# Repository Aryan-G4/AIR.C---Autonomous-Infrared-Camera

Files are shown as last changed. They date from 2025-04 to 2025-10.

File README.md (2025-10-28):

# AIDA: Automated Infrared Detection Aperture



A self-controlled, fire-detecting robot that uses infrared imaging and wireless communication to identify and alert the presence of fire in real time and wirelessly report it to a host computer.  
This project combines mechanical motion, embedded firmware, and networked communication into a compact autonomous system.
It has been designed with the inspiration of removing multiple traditional ceiling fire detectors, replacing them with one robot to monitor an entire room.
---

## Overview


The robot continuously rotates back and forth with a 360 Degree angle using a stepper motor while scanning its surroundings with an infrared camera module.  
When a fire source is detected, it stops rotating and sends a wireless alert to another ESP32 reciever using the ESP-NOW protocol. 
Multiple Fire Monitors can transmit to the reciever 

---

## Features

- 360° autonomous rotation via stepper motor control (NEMA17 + TP339 controller)
- Real-time fire detection using an **MLX90640 infrared camera**  
- Wireless communication via **ESP-NOW** between two ESP32 devkits  
- Powered by a **5V portable phone charger** for mobility  and free rotation, as well as a stepper motor driver powered by a +24V wall adapter
- Automatic halt and alert transmission upon fire detection  
- Modular hardware architecture for easy debugging and extension  

---
## Solidworks model (3D printed)



## Physical Model



## Hardware Components

| Component | Description | Purpose |
|---|---|---|
| **ESP32 DevKit V1** | Wi-Fi + Bluetooth microcontroller | Main processing and communication unit |
| **MLX90640 IR Camera** | 32×24 thermal imaging sensor | Detects fire via infrared radiation |
| **TP339 Stepper Motor Driver** | Stepper control interface | Controls swivel rotation of the robot |
| **Stepper Motor (NEMA 17)** | Bipolar motor | Rotates the robot base |
| **5V Portable Power Bank** | External USB supply | Powers the ESP32 and all connected low-voltage peripherals |
| **Custom Mount and Chassis** | 3D-printed Strucutre | Holds the electronics and allows the NEMA17 to rotate the camera and devkit to monitor the room |

---

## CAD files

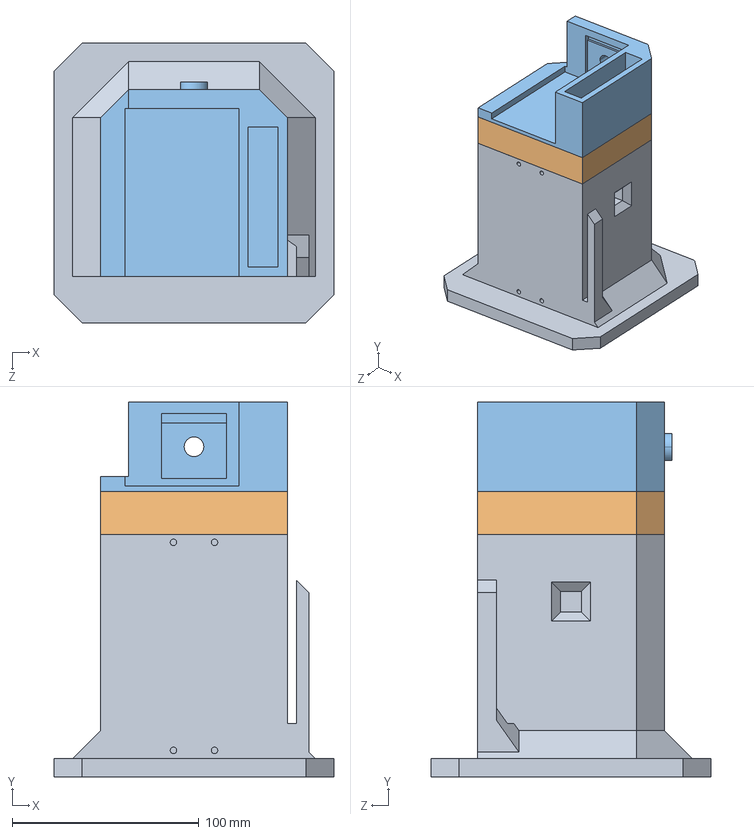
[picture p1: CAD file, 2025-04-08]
Solidworks_CAD_design/3D_Printing_Outbox/STEP_214 Files/Middle_Chassis_v2_UpperChassis_v1.STEP
150.0 x 201.0 x 150.0 mm
BasePrototype
Part1^MASTER-ASSEMBLY
Part2^MASTER-ASSEMBLY

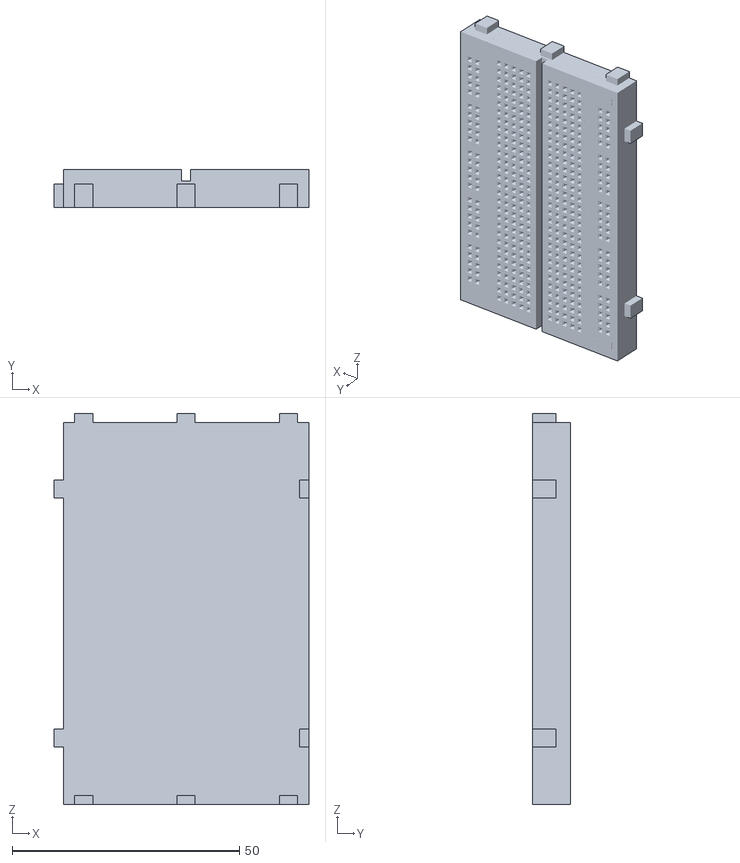
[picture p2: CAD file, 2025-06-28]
Solidworks_CAD_design/Breadboard 400.stl
56.0 x 8.41 x 86.0

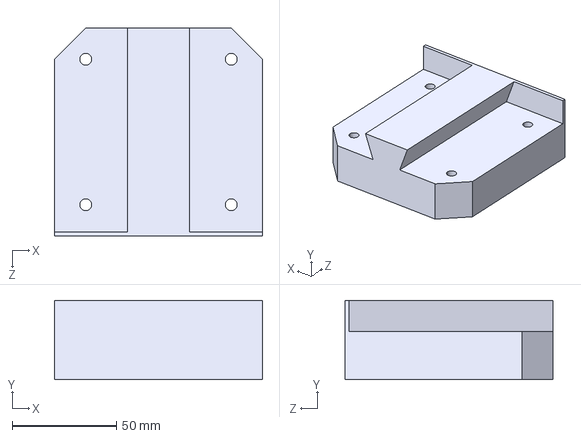
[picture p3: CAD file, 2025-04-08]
Solidworks_CAD_design/3D_Printing_Outbox/STEP_214 Files/Middle_Chassis_v1.STEP
100.0 x 38.0 x 100.0 mm

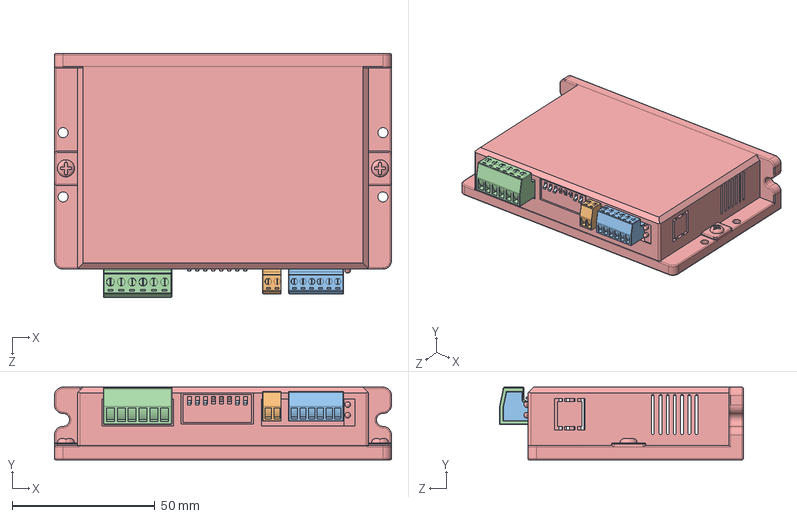
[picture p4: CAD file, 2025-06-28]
Solidworks_CAD_design/DM542T(V4.0).STEP
118.0 x 25.5 x 85.4 mm

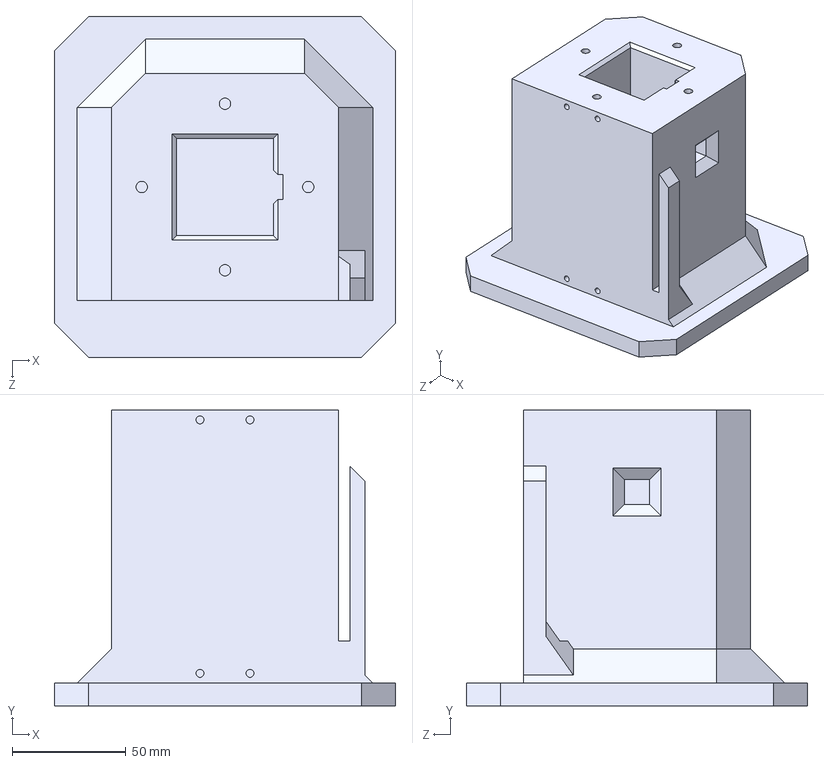
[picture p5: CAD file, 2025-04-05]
Solidworks_CAD_design/3D_Printing_Outbox/STEP_214 Files/Baseprototype_v2_31-03-25.STEP
150.0 x 130.0 x 150.0 mm

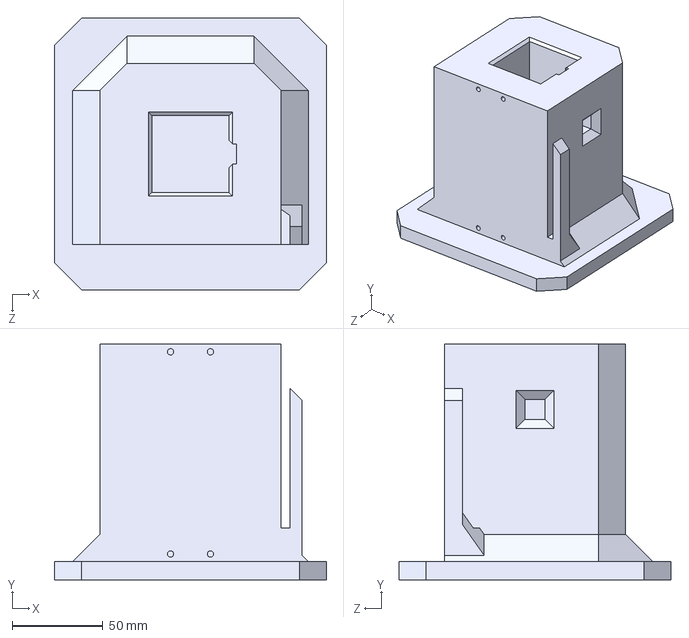
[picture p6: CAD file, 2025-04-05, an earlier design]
Solidworks_CAD_design/3D_Printing_Outbox/STEP_214 Files/Baseprototype_v1_31-03-25.STEP
150.0 x 130.0 x 150.0 mm

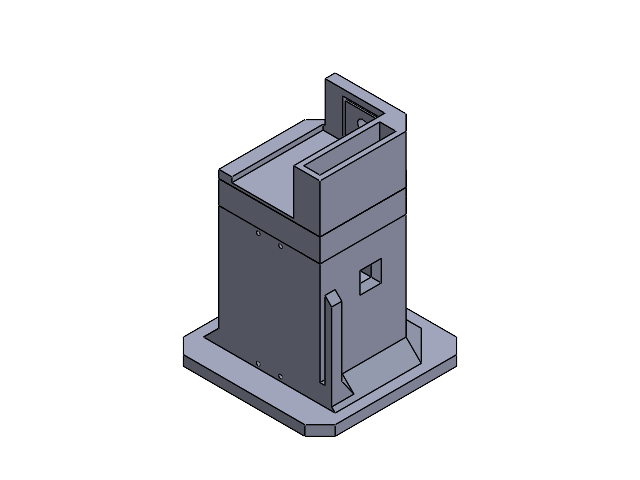
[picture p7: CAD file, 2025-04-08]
Solidworks_CAD_design/MASTER-ASSEMBLY.SLDASM
BasePrototype
Part1^MASTER-ASSEMBLY
Part2^MASTER-ASSEMBLY

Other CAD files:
Solidworks_CAD_design/BasePrototype.SLDPRT
Solidworks_CAD_design/MASTER-ASSEMBLY drawing.SLDDRW

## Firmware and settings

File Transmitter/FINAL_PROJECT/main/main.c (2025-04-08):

#include <stdio.h>
#include "freertos/FreeRTOS.h"
#include "freertos/task.h"
#include "driver/gpio.h"
#include "esp_log.h"

#define TAG "STEPPER_CONTROL"

// Define GPIOs for stepper motor
#define STEP_PIN GPIO_NUM_4  // PULSE pin
#define DIR_PIN  GPIO_NUM_19  // Direction pin

// Function to initialize GPIOs
void init_stepper() {
    gpio_reset_pin(STEP_PIN);
    gpio_reset_pin(DIR_PIN);

    gpio_set_direction(STEP_PIN, GPIO_MODE_OUTPUT);
    gpio_set_direction(DIR_PIN, GPIO_MODE_OUTPUT);

    // Set initial state
    gpio_set_level(STEP_PIN, 0);
    gpio_set_level(DIR_PIN, 1);  // 1 = Forward, 0 = Reverse
}



void app_main() {
    ESP_LOGI(TAG, "Initializing Stepper...");
    init_stepper();

    while (1) {
       for ()
    }
}

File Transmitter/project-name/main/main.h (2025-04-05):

#ifndef MAIN_H
#define MAIN_H

#include <stdint.h>
#include "esp_now.h"

// UART Configuration
#define UART_NUM UART_NUM_0
#define TXD_PIN 17
#define RXD_PIN 16
#define BUF_SIZE 1024

// LED GPIO
#define RED_LED_PIN GPIO_NUM_17
#define GREEN_LED_PIN GPIO_NUM_5
#define YELLOW_LED_PIN GPIO_NUM_16

// PINS FOR MOTOR
#define STEP_PIN GPIO_NUM_4
#define DIR_PIN GPIO_NUM_23

// I2C Configuration
#define I2C_MASTER_SCL_IO 22
#define I2C_MASTER_SDA_IO 21
#define I2C_MASTER_FREQ_HZ 100000
#define I2C_MASTER_PORT I2C_NUM_0
#define DEVICE_ADDR 0x33

// Sensor Configuration
#define NUM_ROWS 24
#define NUM_COLS 32

// Important Register Definitions
#define STATUS_REG 0x8000

// Function Declarations
void uart_init();
void i2c_init();
void print_msg(char* message);
void print_num(char * message, uint8_t num);
uint16_t i2c_read(uint16_t reg);
void i2c_write(uint16_t data, uint16_t reg);

void print_arr(int *arr, int rows, int cols);
void toggleLED();
void on_data_sent(const uint8_t *mac_addr, esp_now_send_status_t status);
void step_motor();
void step_ccw();
void step_cw();


#endif // MAIN_H

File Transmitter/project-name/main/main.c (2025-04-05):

#include <stdio.h>
#include "driver/uart.h"
#include "freertos/FreeRTOS.h"
#include "freertos/task.h"
#include <string.h>
#include "driver/gpio.h"
#include "driver/i2c.h"
#include "wireless_esp.h"
#include "esp_wifi.h"
#include "esp_now.h"
#include "esp_netif.h"
#include "nvs_flash.h"
#include "main.h"
#include "esp_log.h"
//MASTER CODE (Purple ESP)
//  purple ESP32 MAC Address: 08:D1:F9:2A:1B:54


// necessary files for writing code to interact with MLX90640 camera
#include "MLX90640_I2C_Driver.h" 
#include "MLX90640_API.h"

int curr_pos = 0;
int prev_pos = 0;

static const char *TAG = "ESP-NOW MASTER";
// ESP32-NOW Identity
uint8_t receiver_mac[] = {0x81, 0xD1, 0xF9, 0xDD, 0x54, 0x3C}; // REPLACE WITH YOUR SLAVE'S MAC
// Mac Address of the reciever
// float frame[NUM_ROWS*NUM_COLS]; // buffer for full frame of temperatures
// space for eeprom data to be stored
static uint16_t eeMLX90640[832]; //(NUM_ROWS+2)*NUM_COLS -- as described in driver pdf
// pointer to camera frame data already acquired
static uint16_t mlx90640Frame[834];
// pointer to MCU memory where already extracted params for device are stored (params decided by manufacturer)
paramsMLX90640 mlx90640;
static float mlx90640Image[NUM_ROWS*NUM_COLS]; //768
static float mlx90640Image_compare[NUM_ROWS*NUM_COLS]; //768

// uncomment *one* of the below
//#define PRINT_TEMPERATURES
#define PRINT_ASCIIART

void app_main() {
    char message[100];  // we'll use for all our printing 

    // initializing connections
    uart_init(); 
    MLX90640_I2CInit(); 
    wifi_init();
    nvs_flash_init();
    esp_netif_init();
    esp_event_loop_create_default();
    esp_wifi_init(&(wifi_init_config_t)WIFI_INIT_CONFIG_DEFAULT());
    esp_wifi_set_mode(WIFI_MODE_STA);
    esp_wifi_start();

    esp_now_init();

    esp_now_register_send_cb(on_data_sent);
    esp_now_peer_info_t peer = {};
    memcpy(peer.peer_addr, receiver_mac, 6);
    peer.channel = 0;
    peer.encrypt = false;

    if (esp_now_add_peer(&peer) != ESP_OK) {
        ESP_LOGE(TAG, "Failed to add peer\n");
        return;
    }
    sprintf(message, "Wireless Connection Enabled\n");
    esp_now_send(receiver_mac,(uint8_t*)message, sizeof(message));

    vTaskDelay(pdMS_TO_TICKS(3000));

    // set up alarm LED pin
    gpio_reset_pin(RED_LED_PIN);
    gpio_set_direction(RED_LED_PIN, GPIO_MODE_OUTPUT);
    gpio_set_level(RED_LED_PIN,0);

    // set up indication LED pin
    gpio_reset_pin(GREEN_LED_PIN);
    gpio_set_direction(GREEN_LED_PIN, GPIO_MODE_OUTPUT);
    gpio_set_level(GREEN_LED_PIN,0);

    // set up booting up LED pin
    gpio_reset_pin(YELLOW_LED_PIN);
    gpio_set_direction(YELLOW_LED_PIN, GPIO_MODE_OUTPUT);
    gpio_set_level(YELLOW_LED_PIN,1);
    vTaskDelay(pdMS_TO_TICKS(5000));

    // set up motor pins
    gpio_reset_pin(STEP_PIN);
    gpio_set_direction(STEP_PIN, GPIO_MODE_OUTPUT);
    gpio_set_level(STEP_PIN,0);
    gpio_reset_pin(DIR_PIN);
    gpio_set_direction(DIR_PIN, GPIO_MODE_OUTPUT);
    gpio_set_level(DIR_PIN,0);

    // set up one-time settings
    MLX90640_DumpEE (DEVICE_ADDR, eeMLX90640);  // need to dump eeprom to get access the paramters
    MLX90640_SetResolution(DEVICE_ADDR, 0x03);  // 16bit resolution
    int curResolution;
    curResolution = MLX90640_GetCurResolution(DEVICE_ADDR);
    sprintf(message, "Current resultuion=%d bits\n", 16+curResolution);
    print_msg(message);
    MLX90640_SetRefreshRate (DEVICE_ADDR,0x02);         // previously tried 0x05            -- 1 frame per second
    int curRR;
    curRR = MLX90640_GetRefreshRate (DEVICE_ADDR);
    sprintf(message, "Current refresh rate=%d fps\n", curRR);  
    print_msg(message);
    
    MLX90640_SetChessMode (DEVICE_ADDR);    // chess mode is nicer -- grid rather than stacked lines
    int mode;
    mode = MLX90640_GetCurMode(0x33);
    sprintf(message,"current mode(%d)=%s\n",mode,(mode?"chess":"interleaved"));
    print_msg(message);

    MLX90640_ExtractParameters(eeMLX90640,&mlx90640);   // extracting them from the previous eeprom dump
    sprintf(message, "Extracting parameters done!\nVdd=%d\n", mlx90640.vdd25);
    print_msg(message);
    MLX90640_I2CFreqSet(400);

    MLX90640_GetFrameData(DEVICE_ADDR, mlx90640Frame);
    int subPage;
    subPage = MLX90640_GetSubPageNumber(mlx90640Frame);     // this is for testing moreso
    sprintf(message, "current subpage # is %d\n",subPage);
    print_msg(message);
    sprintf(message,"Vdd=%f\n",MLX90640_GetVdd(mlx90640Frame,&mlx90640));        // in data sheet example = -13115
    print_msg(message);

    MLX90640_GetImage(mlx90640Frame, &mlx90640, mlx90640Image);
    sprintf(message, "Device Initialized\n");
    esp_now_send(receiver_mac,(uint8_t*)message, sizeof(message));
    while (1) {
        // printf("In the main loop\n");
        //print_msg("hi\n");
        //uart_write_bytes(UART_NUM, message, strlen(message)); // Send message over UART
        // wirelessmessagetest();
        // read_mac_address();
        gpio_set_level(GREEN_LED_PIN,1);
        gpio_set_level(YELLOW_LED_PIN,0);

        MLX90640_GetFrameData(DEVICE_ADDR, mlx90640Frame);
        float ta = MLX90640_GetTa(mlx90640Frame, &mlx90640);
        sprintf(message, "Ambinet temperature=%f\n", ta);     // in testing = ~29 C
        print_msg(message);

        // gets the ACTUAL (calculated) temperature of object in C
        // emissivity (how reflective obj is) = 0.95
        // reflected temperature (tr) -- in driver pdf says that ta-8 is pretty standard
        MLX90640_CalculateTo(mlx90640Frame, &mlx90640, 0.95, ta-8, mlx90640Image);  
        float t_max=-1000; 
        float t_min=1000;
        for (uint8_t h=0; h<24; h++) {
            for (uint8_t w=0; w<32; w++) {
                float t = mlx90640Image[h*32 + w];
                // storing min/max temps -- for sanity check but also could use to set alarm trigger
                if(t>t_max) t_max=t;
                if(t<t_min) t_min=t;
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

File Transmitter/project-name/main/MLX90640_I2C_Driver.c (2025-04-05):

/**
   @copyright (C) 2017 Melexis N.V.
   Licensed under the Apache License, Version 2.0 (the "License");
   you may not use this file except in compliance with the License.
   You may obtain a copy of the License at
       http://www.apache.org/licenses/LICENSE-2.0
   Unless required by applicable law or agreed to in writing, software
   distributed under the License is distributed on an "AS IS" BASIS,
   WITHOUT WARRANTIES OR CONDITIONS OF ANY KIND, either express or implied.
   See the License for the specific language governing permissions and
   limitations under the License.
*/

// got this file from https://github.com/netzbasteln/MLX90640-Thermocam/blob/master/MLX90640_I2C_Driver.cpp 
// MODIFIED IT: does not require the Arduino library anymore

//#include<Arduino.h>
//#include <Wire.h>

#include "driver/i2c.h"
#include "main.h"
#include "MLX90640_I2C_Driver.h"

void MLX90640_I2CInit()
{
  i2c_config_t conf = {
    .mode = I2C_MODE_MASTER,
    .sda_io_num = I2C_MASTER_SDA_IO,
    .scl_io_num = I2C_MASTER_SCL_IO,
    .sda_pullup_en = GPIO_PULLUP_ENABLE,
    .scl_pullup_en = GPIO_PULLUP_ENABLE,
    .master.clk_speed = I2C_MASTER_FREQ_HZ
  };
  i2c_param_config(I2C_MASTER_PORT, &conf);
  i2c_driver_install(I2C_MASTER_PORT, conf.mode, 0, 0, 0);

}


//Read a number of words from startAddress. Store into Data array.
//Returns 0 if successful, -1 if error
int MLX90640_I2CRead(uint8_t _deviceAddress, uint16_t startAddress, uint16_t nWordsRead, uint16_t *data)
{
  uint8_t sa;                                                        
  uint8_t command[2] = {0,0};

  sa = (_deviceAddress << 1); // shift 1 bit to left to make space for read/write bit
  command[0] = startAddress >> 8;
  command[1] = startAddress & 0x00FF;

  i2c_cmd_handle_t cmd = i2c_cmd_link_create();
  assert(cmd != NULL);

  // is now using the esp32 i2c commands rather than arduino
  // follows the proper sequence of steps in gathering data
  i2c_master_start(cmd);
  //slave address
  i2c_master_write_byte(cmd,sa | I2C_MASTER_WRITE, true);
  //device registers to be read
  i2c_master_write(cmd,command,2,true);

  i2c_master_start(cmd);
  //slave address before streaming
  i2c_master_write_byte(cmd,sa | I2C_MASTER_READ, true);
  //read all bytes -1 terminated with ACK
  i2c_master_read(cmd,(uint8_t*)data,2*nWordsRead-1,0x0);
  //read final byte termated with NACK
  i2c_master_read_byte(cmd,(uint8_t*)data+(2*nWordsRead-1),0x1);
  i2c_master_stop(cmd);
  
  esp_err_t ret = i2c_master_cmd_begin(I2C_MASTER_PORT, cmd, pdMS_TO_TICKS(5000));
  i2c_cmd_link_delete(cmd);
  
  // camera module accesses data using big endian (msb first) but our memory uses little endian (lsb first) 
  // we need to switch order around to be little endian -- otherwise memory will understand it as garbage
  for(int i=0;i<nWordsRead*2;i+=2){
          uint8_t temp_data=*((uint8_t *)data+i); // saving MSB
          *((uint8_t *)data+i)=*((uint8_t *)data+i+1); // setting LSB to go first
          *((uint8_t *)data+i+1)=temp_data; // setting MSB to go second
  }
    
  if(ret != ESP_OK)
  {
      printf("I2C READ ERROR %i\n", ret);
  }

  return ret;   
}


//Set I2C Freq, in kHz
//MLX90640_I2CFreqSet(1000) sets frequency to 1MHz
void MLX90640_I2CFreqSet(int freq)
{
  //i2c.frequency(1000 * freq);
  //Wire.setClock((long)1000 * freq);
  i2c_driver_delete(I2C_MASTER_PORT);
  i2c_config_t conf = {
    .mode = I2C_MODE_MASTER,
    .sda_io_num = I2C_MASTER_SDA_IO,
    .scl_io_num = I2C_MASTER_SCL_IO,
    .sda_pullup_en = GPIO_PULLUP_ENABLE,
    .scl_pullup_en = GPIO_PULLUP_ENABLE,
    .master.clk_speed = (freq*1000)
  };
  i2c_param_config(I2C_MASTER_PORT, &conf);
  i2c_driver_install(I2C_MASTER_PORT, conf.mode, 0, 0, 0);

  
}

//Write two bytes to a two byte address
int MLX90640_I2CWrite(uint8_t _deviceAddress, uint16_t writeAddress, uint16_t data){
      
  uint8_t sa;
  uint8_t command[4] = {0,0,0,0};
  static uint16_t dataCheck;
  

  sa = (_deviceAddress << 1);
  command[0] = writeAddress >> 8;
  command[1] = writeAddress & 0x00FF;
  command[2] = data >> 8;
  command[3] = data & 0x00FF;

  i2c_cmd_handle_t cmd = i2c_cmd_link_create();
  i2c_master_start(cmd);
  i2c_master_write_byte(cmd,sa | I2C_MASTER_WRITE, true);
  i2c_master_write(cmd,command,4,true);
  i2c_master_stop(cmd);

  esp_err_t ret = i2c_master_cmd_begin(I2C_NUM_0, cmd, pdMS_TO_TICKS(500));
  i2c_cmd_link_delete(cmd);

  if(ret != ESP_OK)
  {
      printf("I2C WRITE ERROR\n");
  }
  
  MLX90640_I2CRead(_deviceAddress,writeAddress,1, &dataCheck);
  if ( dataCheck != data)
  {
//    printf("MLX90640_I2CWrite: The write request didn't stick\n");
//    printf("Written 0x%04x; received 0x%04x\n",data,dataCheck);
    return -2;
  }   
  
  return 0;
}

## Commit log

2025-03-20 Added Sanity Check with UART message and LED flash to Transmitter
2025-03-20 Added i2c init() and print msg fct
2025-03-20 IMPLEMENTED I2C read!!! Reading from lab4 rtc
2025-03-21 implemented i2c_write, testing it with changing 4th iteration in main while, made fixes to print_arr regarding str type
    [main.c]
2025-03-21 Updated code to read MLX camera (not working)
    [main.c]
2025-03-21 Updated I2C command to work with MLX
    register value is not updating, but i2c is succeeding
2025-03-21 added code to read all registers
    -we have determined the camera is defective and have ordered a new one
2025-03-22 Added Wireless_esp.c, wireless.h, and main.h for linking
    Added separate .c and .h files to allow for code development and organization on another file. This file will mainly contain the wireless communication functionality and use for our esp32 boards usin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
2025-03-24 Modified wireless files and added wifi_init()
2025-03-26 Added Arduino library project and pulled Arduino.h
2025-04-01 Added Arduino Code, Wifi capabilities, and started Solidworks model
    [BasePrototype.SLDPRT, Baseprototype_v1_31-03-25.STEP, Baseprototype_v2_31-03-25.STEP]
2025-04-05 adding necessary driver files for final project
2025-04-08 Finished CAD model
    [MASTER-ASSEMBLY.SLDASM, Middle_Chassis_v1.STEP, Middle_Chassis_v2_UpperChassis_v1.STEP]
2025-06-28 Added 3d model files
    [Breadboard 400.stl, DM542T(V4.0).STEP, MASTER-ASSEMBLY drawing.SLDDRW]
2025-10-28 Delete sample project details from README
    Removed sample project information from README.md.
